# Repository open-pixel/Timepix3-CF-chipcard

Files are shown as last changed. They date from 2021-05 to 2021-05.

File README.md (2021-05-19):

# Timepix3-CF-chipcard
A compact Open Hardware chipboard for the Timepix3 chip from the [Medipix Collaboration](https://medipix.web.cern.ch/home) reusing the CompactFlash form factor.

Open the project file `TPX3_CF_chipcard.kicad_pro` in [KiCad V5.99 (*nightly version*)](https://www.kicad.org/download/) or the future version V6 once it is released. 

This project is licensed uner the CERN Open Hardware License: [CERN-OHL-P v2](LICENSE)

#### TODO:
- add more description and images
- 3D custom model files for the card enclosure and KiCad renderings
- update schematic with part order numbers

Author:
[Oliver Keller](https://www.github.com/ozel) (CERN/University of Geneva) 2021

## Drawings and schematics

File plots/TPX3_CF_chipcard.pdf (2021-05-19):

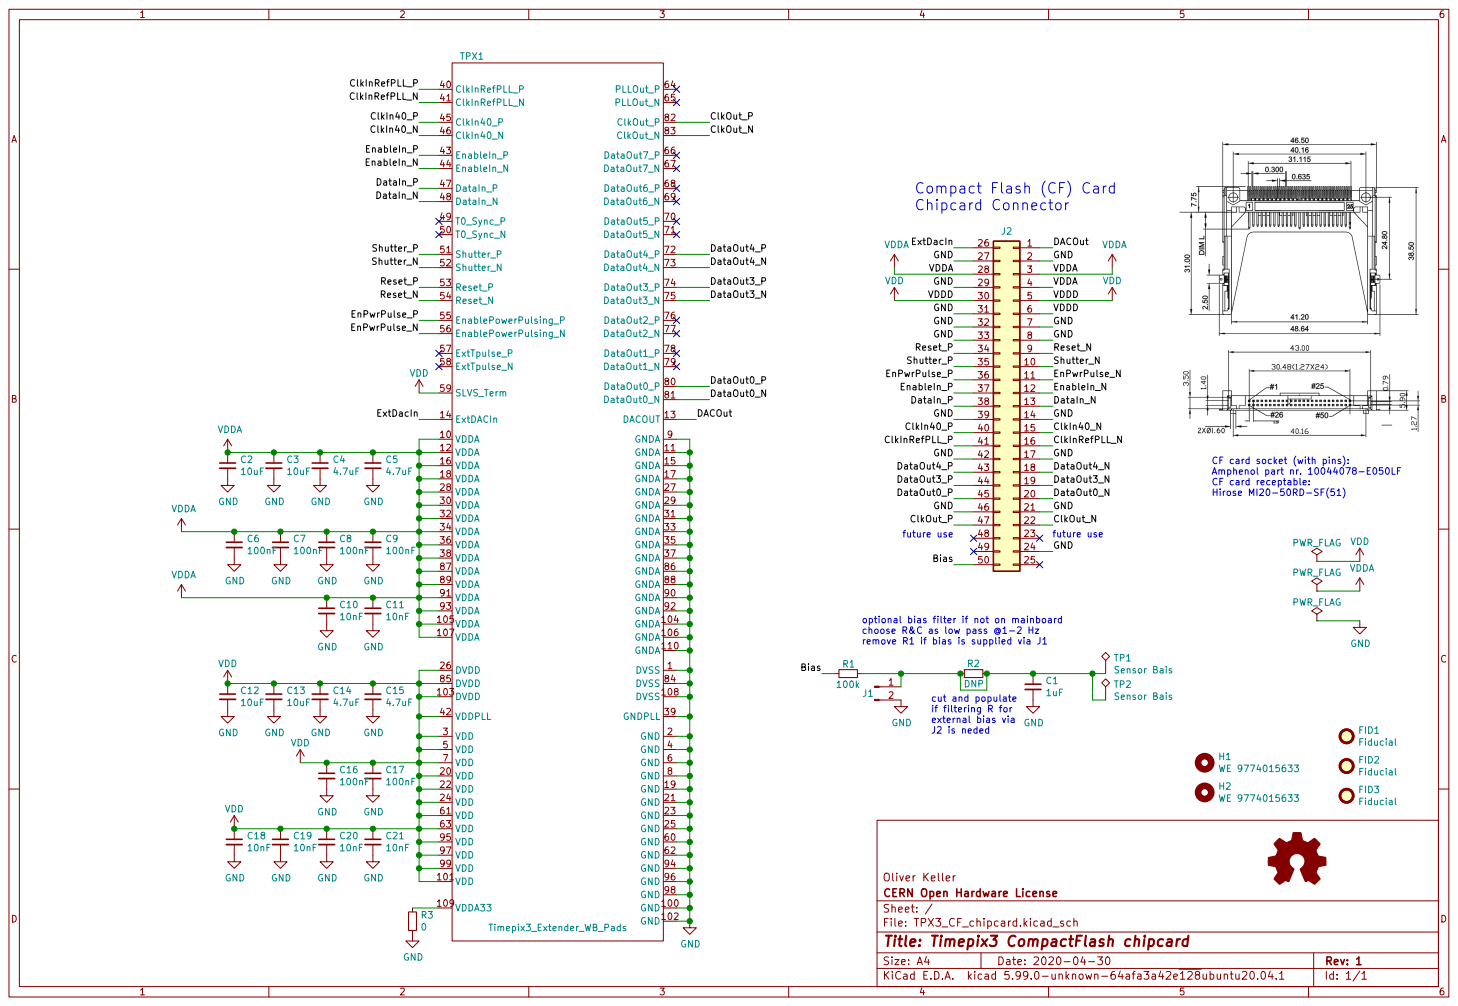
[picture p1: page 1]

Bias Compact Flash (CF) Card
Chipcard Connector

TP2 Sensor Bais GND GND

optional bias filter if not on mainboard
choose R&C as low pass @1-2 Hz
remove R1 if bias is supplied via J1

Id: 1/1 Title: Timepix3 CompactFlash chipcard

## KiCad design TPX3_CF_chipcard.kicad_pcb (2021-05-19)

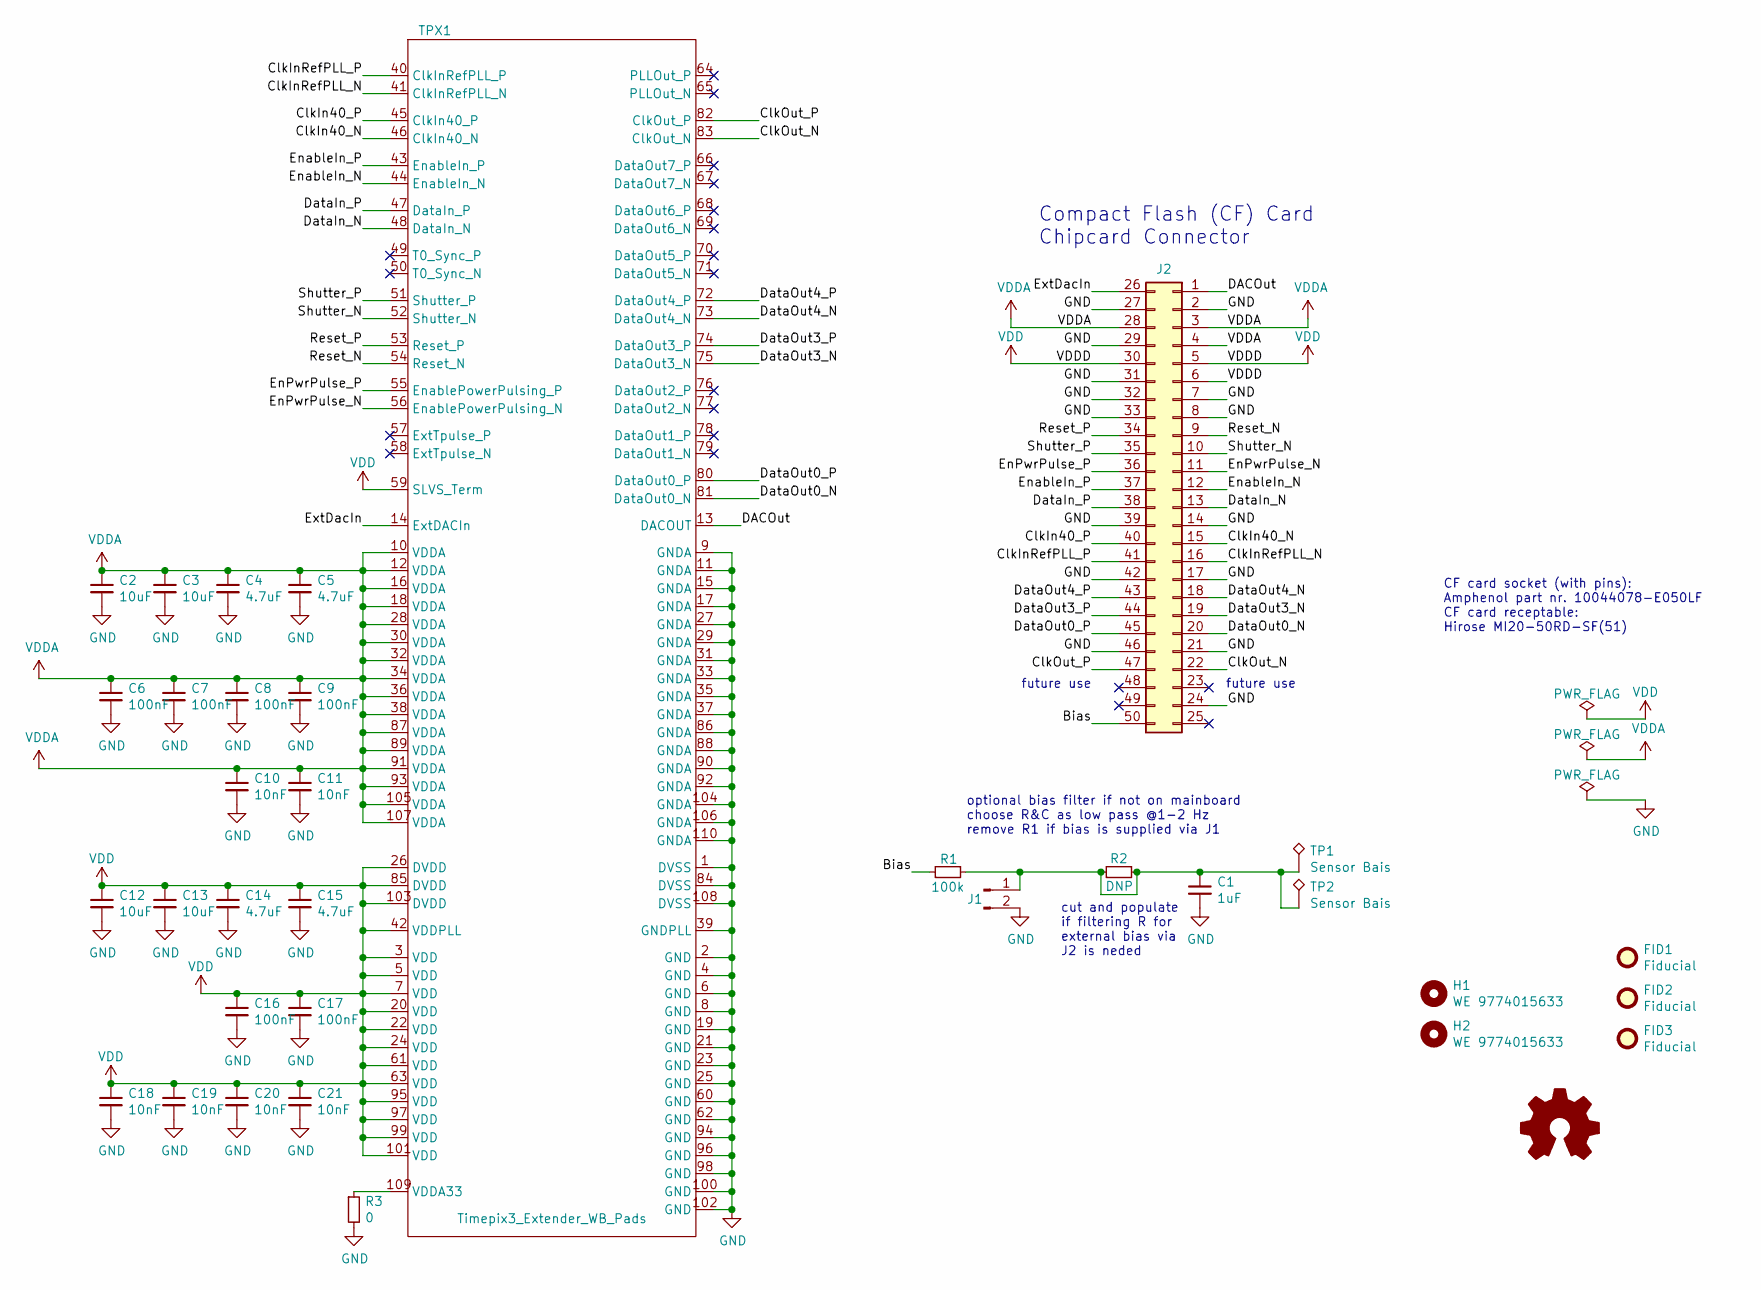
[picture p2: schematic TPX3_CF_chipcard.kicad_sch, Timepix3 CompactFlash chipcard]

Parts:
C1: 1uF; C_0805_2012Metric
C2, C3, C12, C13: 10uF; C_1206_3216Metric
C4, C5, C14, C15: 4.7uF; C_0805_2012Metric
C6, C7, C8, C9, C16, C17: 100nF; C_0402_1005Metric
C10, C11, C18, C19, C20, C21: 10nF; C_0402_1005Metric
FID1, FID2, FID3: Fiducial; Fiducial_0.75mm_Mask1.5mm
H1, H2: WE 9774015633; MountingHole_2.1mm
J1: Conn_01x02_Male; PinHeader_1x02_P2.54mm_Vertical
J2: MI20-50RD-SF(51); CF-Card_Hirose_MI20-50RD-SF(51)
LOGO1: Logo_Open_Hardware_Small; OSHW-Symbol_6.7x6mm_Copper
R1: 100k; R_0603_1608Metric
R2: DNP; R_0603_1608Metric
R3: 0; R_0603_1608Metric
TP1, TP2: Sensor Bais; TestPoint_Pad_2.0x2.0mm
TPX1: Timepix3_Extender_WB_Pads; Timepix3_lowcostWBpads

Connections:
/Bias: J2.50, R1.2
/ClkIn40_N: J2.15, TPX1.46 (ClkIn40_N)
/ClkIn40_P: J2.40, TPX1.45 (ClkIn40_P)
/ClkInRefPLL_N: J2.16, TPX1.41 (ClkInRefPLL_N)
/ClkInRefPLL_P: J2.41, TPX1.40 (ClkInRefPLL_P)
/ClkOut_N: J2.22, TPX1.83 (ClkOut_N)
/ClkOut_P: J2.47, TPX1.82 (ClkOut_P)
/DACOut: J2.1, TPX1.13 (DACOUT)
/DataIn_N: J2.13, TPX1.48 (DataIn_N)
/DataIn_P: J2.38, TPX1.47 (DataIn_P)
/DataOut0_N: J2.20, TPX1.81 (DataOut0_N)
/DataOut0_P: J2.45, TPX1.80 (DataOut0_P)
/DataOut3_N: J2.19, TPX1.75 (DataOut3_N)
/DataOut3_P: J2.44, TPX1.74 (DataOut3_P)
/DataOut4_N: J2.18, TPX1.73 (DataOut4_N)
/DataOut4_P: J2.43, TPX1.72 (DataOut4_P)
/EnPwrPulse_N: J2.11, TPX1.56 (EnablePowerPulsing_N)
/EnPwrPulse_P: J2.36, TPX1.55 (EnablePowerPulsing_P)
/EnableIn_N: J2.12, TPX1.44 (EnableIn_N)
/EnableIn_P: J2.37, TPX1.43 (EnableIn_P)
/ExtDacIn: J2.26, TPX1.14 (ExtDACIn)
/Reset_N: J2.9, TPX1.54 (Reset_N)
/Reset_P: J2.34, TPX1.53 (Reset_P)
/Shutter_N: J2.10, TPX1.52 (Shutter_N)
/Shutter_P: J2.35, TPX1.51 (Shutter_P)
GND: C1.2, C2.2, C3.2, C4.2, C5.2, C6.2, C7.2, C8.2, C9.2, C10.2, C11.2, C12.2, C13.2, C14.2, C15.2, C16.2, C17.2, C18.2, C19.2, C20.2, C21.2, J1.2, J2.2, J2.7, J2.8, J2.14, J2.17, J2.21, J2.24, J2.27, J2.29, J2.31, J2.32, J2.33, J2.39, J2.42, J2.46, R3.2, TPX1.1 (DVSS), TPX1.2 (GND), TPX1.4 (GND), TPX1.6 (GND), TPX1.8 (GND), TPX1.9 (GNDA), TPX1.11 (GNDA), TPX1.15 (GNDA), TPX1.17 (GNDA), TPX1.19 (GND), TPX1.21 (GND), TPX1.23 (GND), TPX1.25 (GND), TPX1.27 (GNDA), TPX1.29 (GNDA), TPX1.31 (GNDA), TPX1.33 (GNDA), TPX1.35 (GNDA), TPX1.37 (GNDA), TPX1.39 (GNDPLL), TPX1.60 (GND), TPX1.62 (GND), TPX1.84 (DVSS), TPX1.86 (GNDA), TPX1.88 (GNDA), TPX1.90 (GNDA), TPX1.92 (GNDA), TPX1.94 (GND), TPX1.96 (GND), TPX1.98 (GND), TPX1.100 (GND), TPX1.102 (GND), TPX1.104 (GNDA), TPX1.106 (GNDA), TPX1.108 (DVSS), TPX1.110 (GNDA)
unnamed: C1.1, J1.1, R1.1, R2.1, R2.2, TP1.1, TP2.1
unnamed: R3.1, TPX1.109 (VDDA33)
VDD: C12.1, C13.1, C14.1, C15.1, C16.1, C17.1, C18.1, C19.1, C20.1, C21.1, J2.5, J2.6, J2.30, TPX1.3 (VDD), TPX1.5 (VDD), TPX1.7 (VDD), TPX1.20 (VDD), TPX1.22 (VDD), TPX1.24 (VDD), TPX1.26 (DVDD), TPX1.42 (VDDPLL), TPX1.59 (SLVS_Term), TPX1.61 (VDD), TPX1.63 (VDD), TPX1.85 (DVDD), TPX1.95 (VDD), TPX1.97 (VDD), TPX1.99 (VDD), TPX1.101 (VDD), TPX1.103 (DVDD)
VDDA: C2.1, C3.1, C4.1, C5.1, C6.1, C7.1, C8.1, C9.1, C10.1, C11.1, J2.3, J2.4, J2.28, TPX1.10 (VDDA), TPX1.12 (VDDA), TPX1.16 (VDDA), TPX1.18 (VDDA), TPX1.28 (VDDA), TPX1.30 (VDDA), TPX1.32 (VDDA), TPX1.34 (VDDA), TPX1.36 (VDDA), TPX1.38 (VDDA), TPX1.87 (VDDA), TPX1.89 (VDDA), TPX1.91 (VDDA), TPX1.93 (VDDA), TPX1.105 (VDDA), TPX1.107 (VDDA)

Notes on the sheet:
optional bias filter if not on mainboard choose R&C as low pass @1-2 Hz remove R1 if bias is supplied via J1
Compact Flash (CF) Card Chipcard Connector
cut and populate if filtering R for external bias via J2 is neded
future use
CF card socket (with pins): Amphenol part nr. 10044078-E050LF CF card receptable: Hirose MI20-50RD-SF(51)

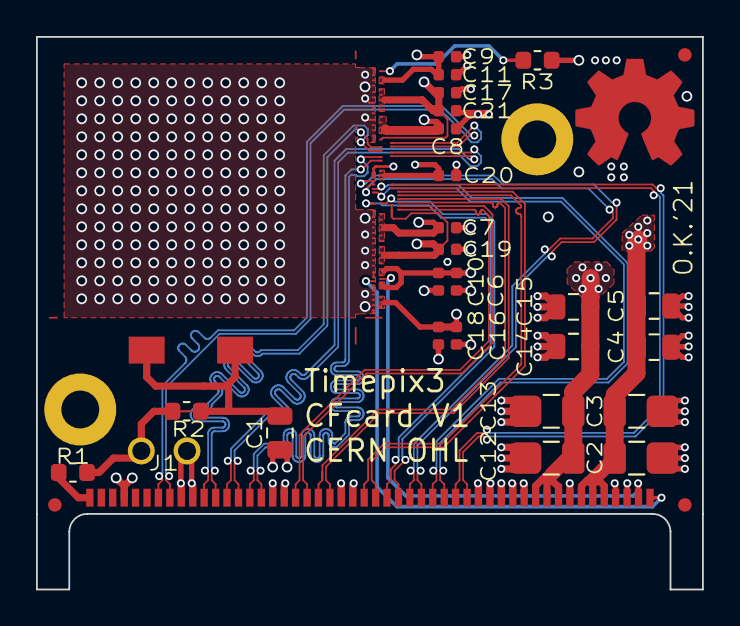
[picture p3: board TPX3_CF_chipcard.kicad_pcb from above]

Board: 4 copper layers, 37.0 x 30.7 mm, 35 parts (0 on the bottom side), 30 nets.
